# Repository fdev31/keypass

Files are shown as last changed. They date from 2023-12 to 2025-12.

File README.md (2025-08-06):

KeyPass helps you keep secure passwords

# Features

- Manages your passwords **up to 31 characters**
- Simple: minimal user interface, polished UX
- **Offline**: Can work 100% without internet/cloud
- Secure: all you need is to remember a passphrase, no data is saved as clear text
- Safe: **backup** your passwords and **restore** them at any time
- Zero requirement: no application needed
    - **Detected as a USB keyboard**
    - Controlled by your phone
    - Shows the UI via **WiFi** with minimal user interaction
- Just works (no software or specific hardware support required)
    - Boot / Logon / BitLocker support
- **BLE** control
- Improved UX using the [phone app](https://github.com/fdev31/KeyPassBLE/)
- Simple design, easy to make

# To be improved

- More keyboard layouts
- iPhone/iOS app (Technically available, just needs to be built.)

# Requirements

- ESP32 C3 super mini (any controller with Wifi and Serial will do, but an Espressif will require little or no code change)
    - supports the version with a built-in 0.42" OLED screen
- (optional) 3D printer
- A CH9329 device

# Installation

- Install platformIO
- Replace the "12345678" WIFI password in `src/configuration.h` with your own (you can also change it later on)
- run "build & upload" in GUI or `pio run --target=upload` in CLI

# Usage

- Plug to the USB port of the device asking for a password
- Connect to "KeyPass" Wifi hotspot
- Follow the instructions to open the interface, or try to connect to any website
- Press on the entry you want to login into, or add a new entry (name & password)
- Several keymaps can be supported (for now French and American keyboard layouts are supported)

# DIY

- Get a microcontroller which has a serial interface and WiFi
- Get some CH9329 device (in Mode 1 : `MOD0` set to `LOW`)
- Connect the serial of the micro controller to the input of CH9329
- Connect GND and 5V together
- If not using and ESP32 C3, make some minor `platformio.ini` & code changes

Optionally:
- Use KeyPass1.stl and KeyPass2.stl in the "casing" folder and print your own!

# Special thanks

- [Captive portal](https://github.com/CDFER/Captive-Portal-ESP32/) for showing all the tricks for Captive portals and giving a good code base
- [ESP Flasher](https://espressif.github.io/esptool-js/) (0x10000)

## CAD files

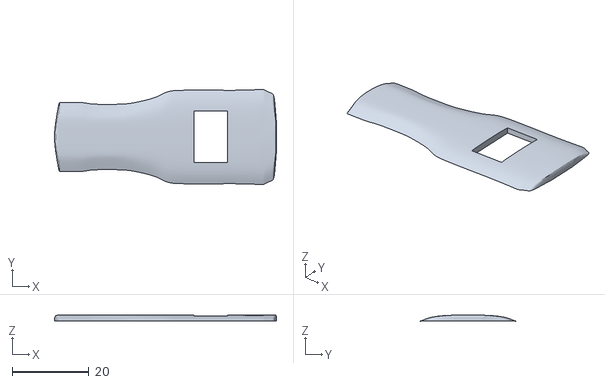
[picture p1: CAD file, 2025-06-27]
casing/KeyPass3-topcover.stl
57.8 x 24.7 x 1.63

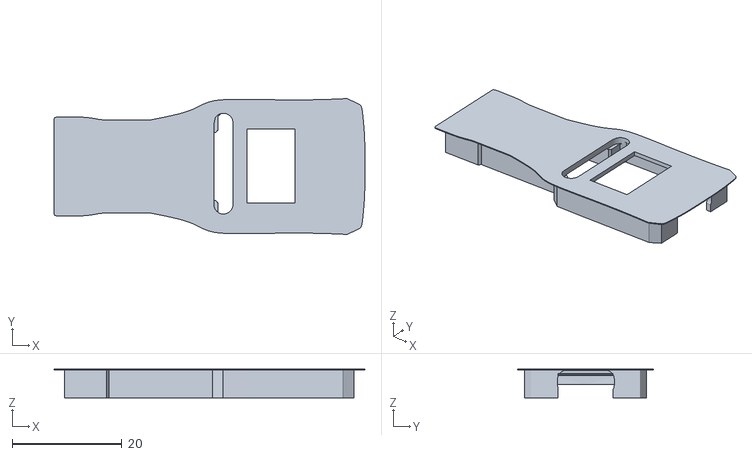
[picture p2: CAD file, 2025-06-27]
casing/KeyPass3-innershell.stl
56.7 x 24.8 x 5.20

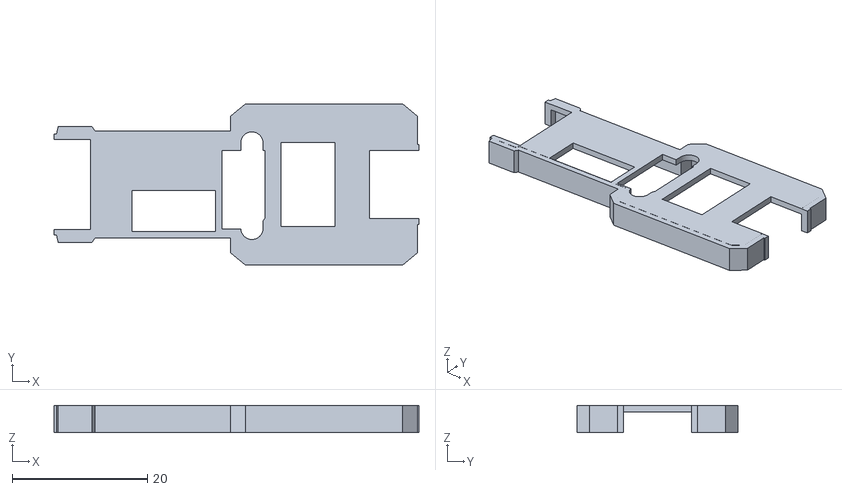
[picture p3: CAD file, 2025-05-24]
casing/KeyPass2.stl
54.0 x 23.9 x 4.03

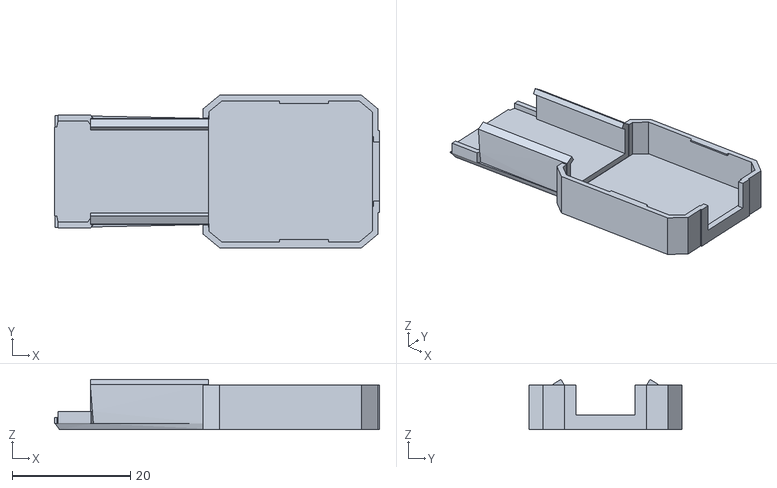
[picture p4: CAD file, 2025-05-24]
casing/KeyPass1.stl
55.0 x 25.9 x 8.51

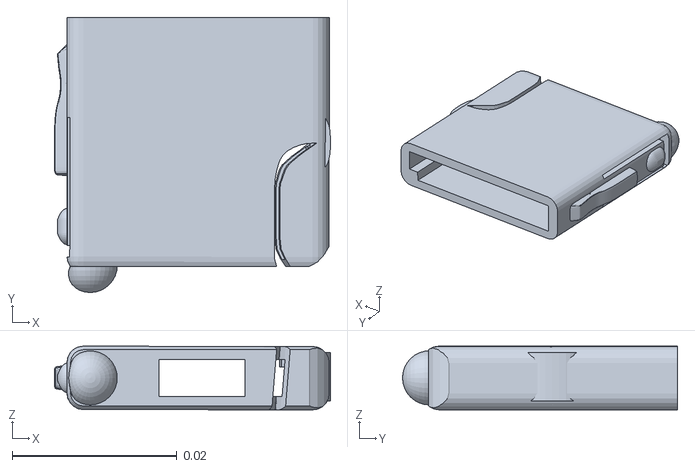
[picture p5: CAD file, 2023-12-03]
casing/USBKeyPass-body.stl
0.0335 x 0.0334 x 0.00773

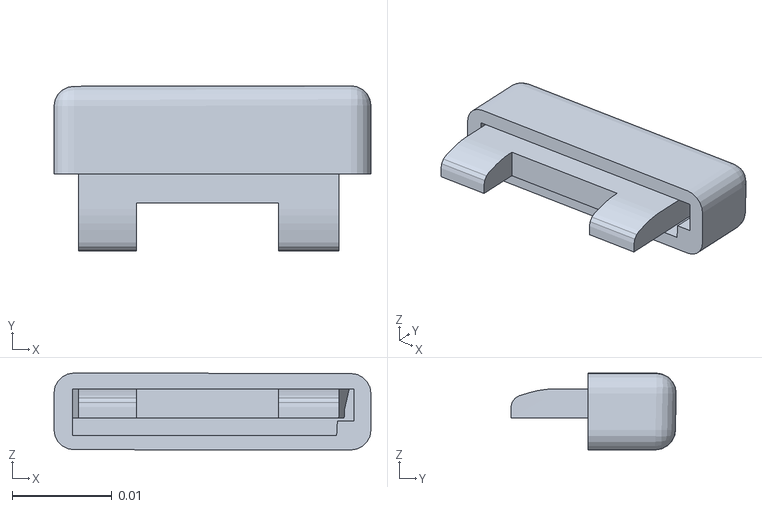
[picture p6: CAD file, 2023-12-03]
casing/USBKeyPass-lid.stl
0.0318 x 0.0166 x 0.00773

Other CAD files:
casing/USBKeyPass.blend
casing/casing-final.blend

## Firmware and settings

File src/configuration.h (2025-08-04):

#include "constants.h"
#include "version.h"
#ifndef _CONFIGURATION_H_
#define _CONFIGURATION_H_

#define SDA_PIN 5
#define SCL_PIN 6

const unsigned long AUTOSLEEP_TIMEOUT = 100 * 1000; // auto-sleep delay
const unsigned long SLEEP_WAKE_TIME = 10 * 1000;    // busy period in sleep mode
const unsigned long SLEEP_TIME = 500; // sleep period in sleep mode
// Max wifi clients, keep it low for security, or higher for dev
#define MAX_CLIENTS 1
#define WIFI_CHANNEL 6
// FYI The SSID can't have a space in it.
#define DEFAULT_WIFI_SSID "KeyPass"
// At least 8 chars
#define DEFAULT_WIFI_PASSWORD "12345678" // set to NULL for no password

#define ENABLE_FULL_ENCRYPTION 1 // also encrypt names
#define ENABLE_BLUETOOTH true
#define ENABLE_HTTP true
#ifndef ENABLE_GRAPHICS
#define ENABLE_GRAPHICS false
#endif

#ifndef HW_TYPE
#define HW_TYPE 1
#endif

#define STRINGIFY(x) #x
#define TOSTRING(x) STRINGIFY(x)

#pragma message("*** HW_TYPE is set to " TOSTRING(HW_TYPE))

#if HW_TYPE == 0 // standard device
#define BUGGY_OFFSET_X 0
#define BUGGY_OFFSET_Y 0
#elif HW_TYPE == 1         // custom device A
#define BUGGY_DISPLAY true // Some devices have a non-standard control
#define BUGGY_OFFSET_X 30
#define BUGGY_OFFSET_Y 12
#elif HW_TYPE == 2         // custom device B
#define BUGGY_DISPLAY true // Some devices have a non-standard control
#define BUGGY_OFFSET_X 28
#define BUGGY_OFFSET_Y 24
#endif

#define DEBUG 0

// WARN: deprecated options (non default will break)
#define USE_EEPROM_API 0
#define USE_CH9329 1
#define FLIP_SCREEN 1
#endif

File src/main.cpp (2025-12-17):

#include "configuration.h"
#include "settings.h"
#if ENABLE_BLUETOOTH
#include "bluetooth.h"
#endif
#if ENABLE_HTTP
#include "captive.h"
#include "http.h"
#endif
#include "WiFi.h"
#include "bootloader_random.h"
#include "driver/adc.h"
#include "driver/rtc_io.h"
#include "esp_bt.h"
#include "esp_sleep.h"
#include "esp_wifi.h"
#include "graphics.h"
#include "password.h"
#include <Arduino.h>
#include <Wire.h>
#include <esp_sleep.h> // Add this for sleep functions
#include <esp_wifi.h>  // Add this for esp_wifi_set_ps

unsigned long lastClientTime;

int sleeping = 0;
int graphics_initialized = 1;

unsigned long boot_time = 0;
bool version_displayed = false;

void ping() {
  lastClientTime = millis();
  sleeping = 0;
}

extern void sendHIDInit();

void setup() {
  esp_sleep_disable_wakeup_source(ESP_SLEEP_WAKEUP_ALL);
  sendHIDInit();
  bootloader_random_enable();
  srand(millis());
#if ENABLE_GRAPHICS
  graphicsSetup();
  char version_string[50];
  snprintf(version_string, sizeof(version_string), "%d@%s", HW_TYPE, VERSION);
  printText(1, version_string);
  boot_time = millis();
  version_displayed = true;
#endif
#if USE_CH9329
  Serial.begin(9600);
#else
  Serial.begin(115200);
#endif
#if ENABLE_HTTP
  captiveSetup();
  setupHttp(server);
  setIconStatus(ICON_WIFI, true);
#endif
#if ENABLE_BLUETOOTH
  bluetoothSetup();
  setIconStatus(ICON_BLUETOOTH, true);
#endif
  lastClientTime = millis();
  Wire.begin(SDA_PIN, SCL_PIN);
}
void loop() {
  int should_sleep = millis() - lastClientTime >=
                     (sleeping ? SLEEP_WAKE_TIME : AUTOSLEEP_TIMEOUT);

  if (!should_sleep) {
#if ENABLE_HTTP
    captiveLoop();
    yield();
#endif
#if ENABLE_BLUETOOTH
    bluetoothLoop();
    yield();
#endif
#if ENABLE_GRAPHICS
    if (version_displayed && (millis() - boot_time > 2000)) {
      printText(1, "  _(^-^)_");
      version_displayed = false;
    }
    if (!sleeping) {
      if (!graphics_initialized) {
        graphicsSetup();
        graphics_initialized = 1;
        yield();
      }
      graphicsLoop();
      yield();
    }
#endif
  }
  if (!sleeping && should_sleep) {

    // First put WiFi in power save mode to gracefully reduce activity
    wifi_ps_type_t ps_type = WIFI_PS_MAX_MODEM;
    esp_wifi_set_ps(ps_type);

    yield();
    delay(100); // Give WiFi time to enter power save

    shutdownGraphics();
    yield();
  }

  // Wake-up: reset states
  if (should_sleep || sleeping) {
#if !DEBUG
    esp_deep_sleep_start();
#endif
    lastClientTime = millis();
    graphics_initialized = 0;
    sleeping = 1;
  }
}

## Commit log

2023-11-22 add 3D files
    [USBKeyPass-body.stl, USBKeyPass-lid.stl, USBKeyPass.blend]
2023-11-22 tiny simplification & potential bugfix
    [main.cpp]
2023-12-03 update casing
    [USBKeyPass-body.stl, USBKeyPass-lid.stl, USBKeyPass.blend]
2025-05-16 misc changes towards flexibility - broken
    [main.cpp]
2025-05-17 Fix the regression (not writing to serial)
    [main.cpp]
2025-05-18 move wifi config to configuration.h
    [configuration.h]
2025-05-23 revamp UI
    [configuration.h]
2025-05-23 use preferences instead of EEPROM
    [configuration.h]
2025-05-23 vast improvements & fixes
    [configuration.h]
2025-05-23 WIP: bitbang return
    [configuration.h]
2025-05-24 UX improvement on edit & add
    [configuration.h]
2025-05-24 improvements & fixes
    [configuration.h]
2025-05-24 disable graphics by default
    [configuration.h]
2025-05-24 add support to flip the screen
    [configuration.h]
2025-05-24 integrate a css icon
    [configuration.h]
2025-05-24 add 2 parts exports of the casing
    [KeyPass1.stl, KeyPass2.stl, casing-final.blend]
2025-05-24 rename variable
    [configuration.h]
2025-05-24 add a note
    [casing-final.blend]
2025-05-24 minor fixes
    [configuration.h]
2025-05-24 move channel id to config
    [configuration.h]
2025-05-24 simplify sed command & use a static variable just in case ;)
2025-05-25 rework togglable buttons and settings
2025-06-19 make sleep mode more complex (still reachable via wifi)
    [configuration.h]
2025-06-25 remove delay + remove sleep in DEBUG mode
    [configuration.h]
2025-06-26 add a reset passphrase button
2025-06-27 add newest shells
    [KeyPass3-innershell.stl, KeyPass3-topcover.stl]
2025-07-01 add version (instead of passwd length)
    [configuration.h]
2025-07-01 feat: Configure Android project and add Justfile for automation
    This commit addresses several issues preventing the Android project from building successfully:
    - Updated Java version to 21 in .
    - Accepted Android SDK licenses.
    - Corrected permissions for the Android SDK directory ().
    - Enabled AndroidX by setting in .
    - Added missing placeholder and resource files.
    Additionally, a has been added to automate common development tasks, including:
    - : For initial environment configuration (SDK permissions, licenses, AndroidX).
    - : To clean the build directory.
    - : To build the debug APK.
    - : To install the debug APK on a connected device/emulator.
    - : To launch the application on a connecte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
2025-07-01 move some constants
    [configuration.h]
2025-07-04 feat(android): Add custom app icon and generation script
    Adds a new app icon derived from the `logo.svg` file. This includes:
    - PNG versions of the icon in all standard densities (mdpi, hdpi, xhdpi, xxhdpi, xxxhdpi).
    - Round versions of the icons for devices that use them.
    - Adaptive icon support for modern Android versions, with a white background.
    - A shell script (`scripts/regenerate_icons.sh`) to allow for easy regeneration of all icon assets from the source SVG.
2025-07-06 add latests STL files
2025-07-09 disable bluetooth by default
    [configuration.h]
2025-07-09 remove PIN (not needed anymore)
2025-07-09 will not switch to chacha
2025-07-09 remove pin in front
2025-07-09 encrypt labels too
    [configuration.h]
2025-07-12 make button text not selectable
2025-07-13 add one more char to the test to match current limit
    reclaimed one byte when moving the version out
2025-07-13 enable ESP32 random number generator
2025-07-17 Refactor import & import
    [configuration.h]
2025-07-17 bluetooth :)
    [configuration.h]
2025-07-18 feat: Implement Settings page functionality
    - Add UI elements for "Confirm Actions", "Hide Passwords", "Backup Passwords", "Change WiFi Password", "Reset Passphrase", "Factory Reset", and "Show Passphrase".
    - Implement logic in SettingsActivity.java to handle preferences and send corresponding BLE commands.
    - Display backup data and passphrase in dedicated text areas.
    - Enable/disable buttons based on BLE connection status.
    - Add necessary imports and permission checks for BLE operations.
    - Update indexPage.h (microcontroller related change).
2025-07-18 switch off wifi if BLE connects
2025-07-22 rework buggy displays
    [configuration.h]
2025-08-01 add hw type
    [configuration.h]
2025-08-01 add a version display
    [configuration.h]
2025-08-01 avoid regenerating index when not needed
    [configuration.h]
2025-08-02 deprecate FLIP_SCREEN config
    [configuration.h]
2025-08-03 fix / cleanup
    [configuration.h]
2025-08-03 minor changes
    [configuration.h]
2025-08-03 prepare a build matrix
    [configuration.h]
2025-08-08 Allow setting the device name
2025-10-05 feat(UI/UX): Overhaul UI with hacker theme and improve usability
    This commit introduces a major redesign of the web interface and resolves several key security and usability issues.
    - Replaced the entire CSS with a new theme, featuring a dark background, glowing green text, and scan line effects for a more "hackrish" feel.
    - Updated the settings icon from a star to a gear for better clarity and universal understanding.
    - The password list is now automatically sorted alphabetically by name.
    - The list has been restyled into a numbered, terminal-style menu to improve visual organization and sequence.
    - Added a visible edit button to each password entry, making the edit action discoverable an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
2025-12-17 remove problematic power option
    [main.cpp]
2025-12-17 pin espressif32 framework version
